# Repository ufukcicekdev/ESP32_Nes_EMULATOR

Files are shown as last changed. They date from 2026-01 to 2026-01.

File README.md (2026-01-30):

# 🎮 Anemoia-ESP32 S3 NES Console (Custom Build)

Bu proje, **ESP32-S3** mikrodenetleyicisi üzerinde çalışan, yüksek performanslı ve taşınabilir bir NES emülatörüdür. Orijinal [Anemoia-ESP32](https://github.com/Shim06/Anemoia-ESP32) projesi referans alınarak, özel donanım konfigürasyonuna ve **MAX98357A I2S DAC** ses sistemine göre optimize edilmiştir.

---

## 🚀 Donanım Özellikleri

* **İşlemci:** ESP32-S3 (N16R8 - 16MB Flash / 8MB Octal PSRAM desteği).
* **Ses Çözücü:** MAX98357A I2S DAC (44100Hz Örnekleme Hızı).
* **Depolama:** MicroSD Kart (Ayrı **FSPI** hattı ile çakışmasız hızlı erişim).
* **Ekran:** ILI9341 TFT LCD (**TFT_eSPI** kütüphanesi ile optimize).

---

## 🔌 Pin Bağlantı Şeması

Proje, ekran ve SD kartın aynı veri yolunda çakışmaması için **ayrı pin gruplarını** kullanacak şekilde yapılandırılmıştır.

### 🔊 Ses (MAX98357A I2S)
Ses kalitesini en üst düzeye çıkarmak için dijital I2S protokolü kullanılmıştır.

| MAX98357A Pini | ESP32-S3 GPIO |
| :--- | :--- |
| **BCLK** (Bit Clock) | **17** |
| **LRC** (WS / Clock) | **18** |
| **DOUT** (Data Out) | **21** |

### 💾 MicroSD Kart (FSPI Hattı)
SD kartın stabil çalışması için ayrılmış özel pinler tanımlanmıştır.

| SD Kart Pini | ESP32-S3 GPIO |
| :--- | :--- |
| **MOSI** | **14** |
| **MISO** | **3** |
| **SCLK** | **41** |
| **CS** | **42** |

### 🕹️ Kontrolcü & Buton Takımı
| Fonksiyon | GPIO | Fonksiyon | GPIO |
| :--- | :--- | :--- | :--- |
| **UP** | 16 | **START** | 1 |
| **DOWN** | 38 | **SELECT** | 2 |
| **LEFT** | 39 | **A** | 0 |
| **RIGHT** | 40 | **B** | 20 |

---

## ⚙️ Yazılım Kurulumu

### 1. TFT_eSPI Konfigürasyonu (Kritik!)
Ekran pinlerini tek tek ayarlamakla vakit kaybetmeyin:
* Repoda bulunan `User_Setup.h` dosyasını indirin.
* Bu dosyayı bilgisayarınızdaki `Documents/Arduino/libraries/TFT_eSPI/` klasörünün içine kopyalayıp eskisini değiştirin.
* Bu işlem, ekranınızın donanımla tam uyumlu çalışmasını sağlar.

### 2. Arduino IDE Ayarları
Yüksek FPS ve kararlılık için **Tools** menüsünden şu ayarları yapın:
* **Board:** `ESP32S3 Dev Module`
* **Flash Mode:** `QIO 80MHz`
* **PSRAM:** `OPI PSRAM` (Kartınız desteklemiyorsa Disabled yapın)
* **USB CDC On Boot:** `Disabled`
* **Core Debug Level:** `None`

---

## 🎮 Kullanım Notları

* **Oyun Yükleme:** `.nes` uzantılı oyun dosyalarınızı SD kartın ana dizinine (root) atın.
* **Menüye Dönüş:** Oyun sırasında **START + SELECT** (Pin 1 + Pin 2) tuşlarına aynı anda basarak ana menüye dönebilirsiniz.
* **Ses Kalitesi:** Varsayılan örnekleme hızı **44100Hz**'dir, retro oyunlarda en net ses deneyimini sunar.

---

## 📜 Kaynakça ve Teşekkür
Bu proje geliştirilirken [Anemoia-ESP32](https://github.com/Shim06/Anemoia-ESP32) kaynak kodları kullanılmış, donanımsal pin haritası ve I2S sürücüleri S3 mimarisi için özelleştirilmiştir.

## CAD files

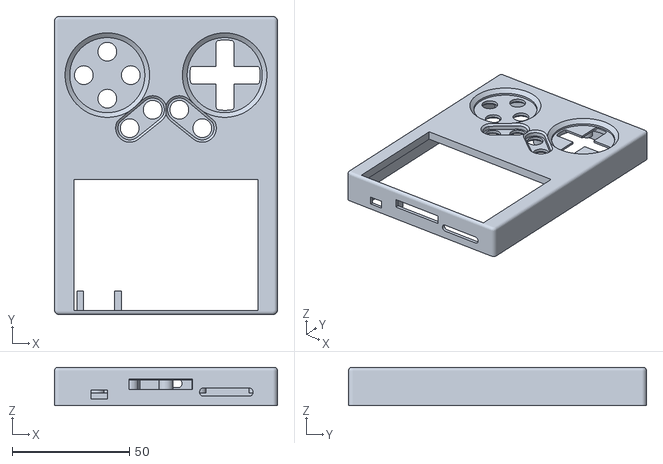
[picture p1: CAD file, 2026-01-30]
STL/anagövde.stl
95.0 x 127.0 x 16.4

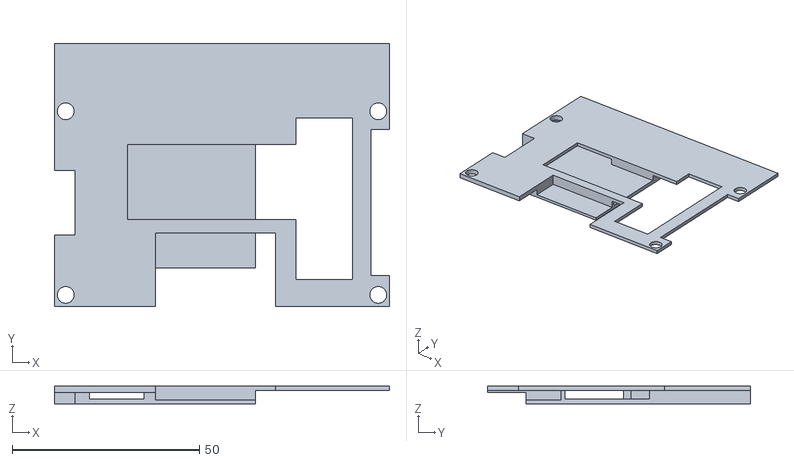
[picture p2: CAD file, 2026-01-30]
STL/ekranve bataryadestek.stl
89.4 x 70.1 x 4.80

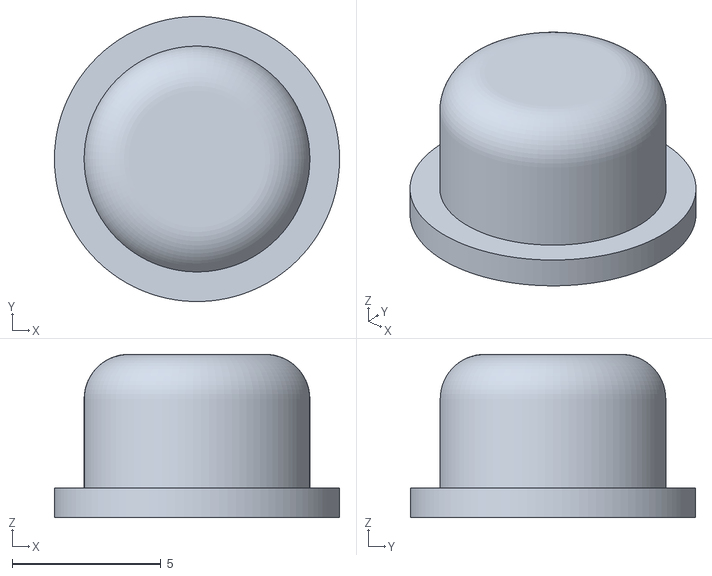
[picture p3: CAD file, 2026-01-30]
STL/buton.stl
9.60 x 9.60 x 5.50

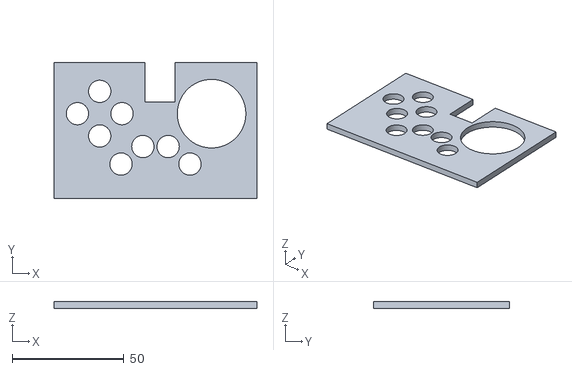
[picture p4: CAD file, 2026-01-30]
STL/3.stl
91.0 x 61.1 x 3.00

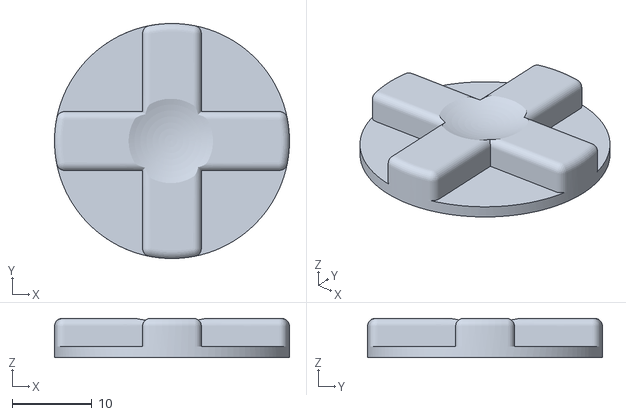
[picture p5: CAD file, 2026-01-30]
STL/dPad.stl
29.4 x 29.4 x 4.92

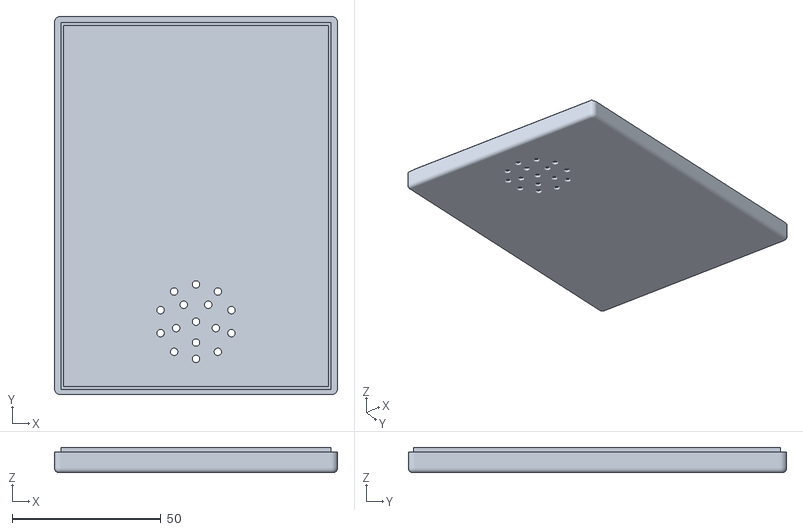
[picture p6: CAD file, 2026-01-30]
STL/arkakapak.stl
95.0 x 127.0 x 8.50

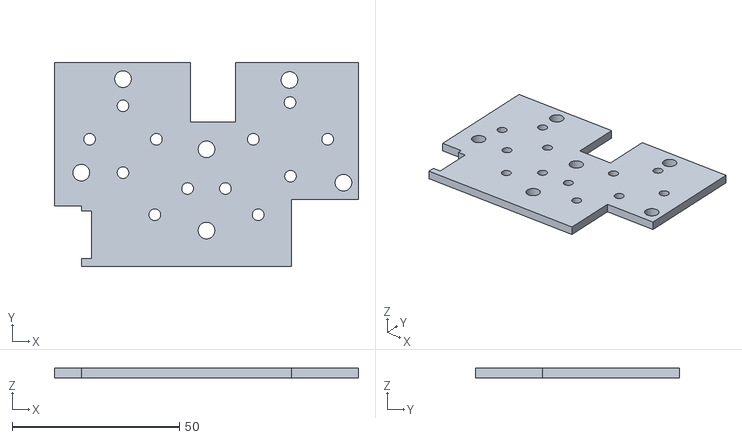
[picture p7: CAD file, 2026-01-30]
STL/2.stl
91.0 x 61.1 x 3.00

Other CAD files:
STL/1.stl

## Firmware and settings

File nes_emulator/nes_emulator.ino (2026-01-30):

#include <Arduino.h>
#include <SD.h>
#include <SPI.h>
#include <string>
#include <vector>

#include "src/core/bus.h"
#include "src/controller.h"
#include "config.h"
#include "driver/i2s.h"
#include "src/ui.h"

// --- SİSTEM AYARLARI (GLOBAL) ---
int globalVolume = 70;      // 0-100 arası
bool showFPS = true;        // FPS Göstergesi
uint16_t themeColor = TFT_CYAN;
float currentFPS = 0;

// --- DURUMLAR ---
enum AppState { STATE_DASHBOARD, STATE_FILE_LIST, STATE_BROWSER, STATE_SETTINGS, STATE_EMULATING };
AppState currentState = STATE_DASHBOARD;

SPIClass SD_SPI(HSPI);
static Bus nes; 
static Cartridge* cart = nullptr; 

std::vector<std::string> fileList;
std::string currentPath = "/";
int selectedIndex = 0;
int scrollOffset = 0;
int dashSelected = 0; 
int settingsSelected = 0; // Ayarlar menüsü seçimi
bool needsRedraw = true;

unsigned long lastInputTime = 0;
const int inputDelay = 150;

// --- 1. SES MOTORU (APU) ---
void setupI2SExternal() {
    i2s_driver_uninstall(I2S_NUM_0);
    i2s_config_t i2s_config = {
        .mode = (i2s_mode_t)(I2S_MODE_MASTER | I2S_MODE_TX),
        .sample_rate = 44100,
        .bits_per_sample = I2S_BITS_PER_SAMPLE_16BIT,
        .channel_format = I2S_CHANNEL_FMT_RIGHT_LEFT,
        .communication_format = I2S_COMM_FORMAT_STAND_I2S,
        .intr_alloc_flags = ESP_INTR_FLAG_LEVEL1 | ESP_INTR_FLAG_IRAM,
        // --- BURASI KRİTİK ---
        .dma_buf_count = 12,   // Buffer sayısını artırarak işlemciye nefes aldır
        .dma_buf_len = 256,   // Buffer boyunu küçülterek gecikmeyi (jitter) azalt
        .use_apll = false,
        .tx_desc_auto_clear = true
    };
    i2s_driver_install(I2S_NUM_0, &i2s_config, 0, NULL);
    
    i2s_pin_config_t pin_config = { 
        .bck_io_num = I2S_BCLK_PIN, 
        .ws_io_num = I2S_LRC_PIN, 
        .data_out_num = I2S_DOUT_PIN, 
        .data_in_num = I2S_PIN_NO_CHANGE 
    };
    i2s_set_pin(I2S_NUM_0, &pin_config);
    i2s_start(I2S_NUM_0); 
    i2s_zero_dma_buffer(I2S_NUM_0);
}

void apuTask(void* param) {
    Apu2A03* apu = (Apu2A03*)param;
    size_t bytes_written;
    i2s_zero_dma_buffer(I2S_NUM_0);

    while (true) {
        for (int i = 0; i < AUDIO_BUFFER_SIZE; i++) {
            // NES Clock Hızı: Eğer ses çok cızırtılıysa 38-42 arasını dene.
            // Bu sayı saniyede kaç NES cycle'ının bir ses örneğine (sample) 
            // dönüşeceğini belirler.
            for(int j = 0; j < 40; j++) {
                apu->clock(); 
            }
            apu->generateSample(); 
        }

        // I2S'e yazarken portMAX_DELAY yerine küçük bir timeout ver
        i2s_write(I2S_NUM_0, 
                  Apu2A03::audio_buffer, 
                  sizeof(Apu2A03::audio_buffer), 
                  &bytes_written, 
                  pdMS_TO_TICKS(10)); 
        
        yield(); 
    }
}
// --- 2. DOSYA YÖNETİMİ ---
void scanDirectory(std::string path, bool sadeceOyun) {
    fileList.clear();
    selectedIndex = 0; scrollOffset = 0;
    if (path != "/") fileList.push_back("..");
    File root = SD.open(path.c_str());
    if(!root) return;
    File file = root.openNextFile();
    while (file) {
        std::string fn = file.name();
        if (fn[0] != '.' && fn.find("_.") == std::string::npos) {
            if (sadeceOyun) { if (fn.find(".nes") != std::string::npos) fileList.push_back(fn); }
            else { fileList.push_back(file.isDirectory() ? "[" + fn + "]" : fn); }
        }
        file = root.openNextFile();
    }
    root.close();
}

// --- 3. EMÜLASYON VE KONTROL ---
void forceExitEmulation(TaskHandle_t &apu_h) {
    if (apu_h != NULL) { vTaskDelete(apu_h); apu_h = NULL; }
    i2s_zero_dma_buffer(I2S_NUM_0);
    if (cart != nullptr) { delete cart; cart = nullptr; }
    digitalWrite(SD_CS_PIN, HIGH);
    lastInputTime = millis(); 
    needsRedraw = true;
}

void emulate(std::string fullPath) {
    cart = new Cartridge(fullPath.c_str());
    if (!cart) return;
    
    UI::clearScreen(); 
    nes.connectScreen(&screen); 
    nes.insertCartridge(cart);
    nes.reset();

    TaskHandle_t apu_h = NULL;
    xTaskCreatePinnedToCore(apuTask, "apuTask", 2028, &nes.cpu.apu, 10, &apu_h, 0);

    unsigned long lastFrameTime = micros();

    while (true) {
        uint16_t in = controllerRead();
        nes.controller = (uint8_t)in;

        // --- OYUN İÇİ SES KONTROLÜ (SELECT + UP/DOWN) ---
        if (in & CONTROLLER::Select) {
            if (in & CONTROLLER::Up && globalVolume < 100) { globalVolume += 2; delay(20); }
            if (in & CONTROLLER::Down && globalVolume > 0) { globalVolume -= 2; delay(20); }
        }

        // FPS Hesapla
        unsigned long now = micros();
        currentFPS = 1000000.0 / (now - lastFrameTime);
        lastFrameTime = now;

        if (in & CONTROLLER::GameMenu) {
            vTaskSuspend(apu_h);
            int mSel = 0; 
            UI::drawPauseMenu(mSel); 
            delay(250);
            bool menuOn = true;
            while(menuOn) {
                uint16_t mi = controllerRead();
                if (mi & CONTROLLER::Up) { mSel--; if(mSel<0) mSel=3; UI::drawPauseMenu(mSel); delay(150); }
                if (mi & CONTROLLER::Down) { mSel++; if(mSel>3) mSel=0; UI::drawPauseMenu(mSel); delay(150); }
                if (mi & CONTROLLER::A) {
                    if (mSel == 0) menuOn = false;
                    if (mSel == 1) { nes.saveState(); menuOn = false; }
                    if (mSel == 2) { nes.loadState(); menuOn = false; }
                    if (mSel == 3) { forceExitEmulation(apu_h); currentState = STATE_FILE_LIST; return; }
                }
                yield();
            }
            UI::clearScreen(); 
            vTaskResume(apu_h);
        }

        if (in & CONTROLLER::Menu) { forceExitEmulation(apu_h); currentState = STATE_DASHBOARD; return; }
        
        nes.clock(); 
        
        if(showFPS) UI::drawFPS(currentFPS);
    }
}

// --- 4. HANDLER FONKSİYONLARI ---
void handleDashboard() {
    uint16_t input = controllerRead();
    if (millis() - lastInputTime < inputDelay) return;
    if (input & CONTROLLER::Left && dashSelected > 0) { dashSelected--; needsRedraw = true; lastInputTime = millis(); }
    else if (input & CONTROLLER::Right && dashSelected < 2) { dashSelected++; needsRedraw = true; lastInputTime = millis(); }
    
    if (needsRedraw) { UI::drawDashboard(dashSelected); needsRedraw = false; }
    
    if (input & CONTROLLER::A) {
        lastInputTime = millis();
        if (dashSelected == 0) { currentPath = "/NES/"; scanDirectory(currentPath, true); currentState = STATE_FILE_LIST; }
        else if (dashSelected == 1) { currentPath = "/"; scanDirectory(currentPath, false); currentState = STATE_BROWSER; }
        else { currentState = STATE_SETTINGS; settingsSelected = 0; }
        needsRedraw = true;
    }
}

void handleSettings() {
    uint16_t in = controllerRead();
    if (millis() - lastInputTime < inputDelay) return;

    if (in & CONTROLLER::Up && settingsSelected > 0) { settingsSelected--; needsRedraw = true; lastInputTime = millis(); }
    if (in & CONTROLLER::Down && settingsSelected < 3) { settingsSelected++; needsRedraw = true; lastInputTime = millis(); }

    // Değer değiştirme (Sağ/Sol)
    if (settingsSelected == 0) { // Ses
        if (in & CONTROLLER::Right && globalVolume < 100) { globalVolume += 5; needsRedraw = true; lastInputTime = millis(); }
        if (in & CONTROLLER::Left && globalVolume > 0) { globalVolume -= 5; needsRedraw = true; lastInputTime = millis(); }
    }
    if (settingsSelected == 1) { // FPS
        if ((in & CONTROLLER::Right || in & CONTROLLER::Left)) { showFPS = !showFPS; needsRedraw = true; lastInputTime = millis(); }
    }

    if (in & CONTROLLER::B || (settingsSelected == 3 && in & CONTROLLER::A)) {
        currentState = STATE_DASHBOARD; needsRedraw = true; lastInputTime = millis(); return;
    }

    if (needsRedraw) {
        UI::drawSettings(settingsSelected, globalVolume, showFPS, themeColor);
        needsRedraw = false;
    }
}

void handleCommonList(bool isGameList) {
    uint16_t in = controllerRead();
    if (millis() - lastInputTime < inputDelay) return;
    if (in & CONTROLLER::Up && selectedIndex > 0) { selectedIndex--; if (selectedIndex < scrollOffset) scrollOffset = selectedIndex; needsRedraw = true; lastInputTime = millis(); }
    else if (in & CONTROLLER::Down && selectedIndex < (int)fileList.size()-1) { selectedIndex++; if (selectedIndex >= scrollOffset + 9) scrollOffset++; needsRedraw = true; lastInputTime = millis(); }
    if (in & CONTROLLER::B) { currentState = STATE_DASHBOARD; needsRedraw = true; lastInputTime = millis(); return; }
    
    if (in & CONTROLLER::A) {
        lastInputTime = millis();
        std::string sel = fileList[selectedIndex];
        if (sel == "..") {
            size_t last = currentPath.find_last_of('/', currentPath.length()-2);
            currentPath = currentPath.substr(0, last+1); scanDirectory(currentPath, isGameList);
            needsRedraw = true;
        } else if (sel[0] == '[') {
            currentPath += sel.substr(1, sel.length()-2) + "/"; scanDirectory(currentPath, isGameList);
            needsRedraw = true;
        } else if (isGameList && sel.find(".nes") != std::string::npos) {
            emulate(currentPath + sel);
            needsRedraw = true;
        }
    }
    
    if (needsRedraw) { 
        UI::drawList(isGameList ? "@withufuk OYUNLAR" : "@withufuk DOSYALAR", fileList, selectedIndex, scrollOffset); 
        needsRedraw = false; 
    }
}

// --- 5. SETUP VE LOOP ---
void setup() {
    Serial.begin(115200); 
    psramInit();
    UI::init(); 
    UI::drawBootScreen();
    setupI2SExternal();
    SD_SPI.begin(SD_SCLK_PIN, SD_MISO_PIN, SD_MOSI_PIN, SD_CS_PIN);
    SD.begin(SD_CS_PIN, SD_SPI, 40000000);
    initController();
}

void loop() {
    switch(currentState) {
        case STATE_DASHBOARD: handleDashboard(); break;
        case STATE_FILE_LIST: handleCommonList(true); break;
        case STATE_BROWSER:   handleCommonList(false); break;
        case STATE_SETTINGS:  handleSettings(); break;
    }
}

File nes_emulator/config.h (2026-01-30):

#ifndef CONFIG_H
#define CONFIG_H


// config.h içine uygun bir yere ekle
extern int globalVolume;       // 0-100 arası
extern bool showFPS;           // FPS sayacı açık mı?
extern uint16_t themeColor;    // Seçili tema rengi

// Kontrolcü Tipi (Buton kullanmadığın için 0 kalsın)
#define CONTROLLER_TYPE 0

// MicroSD kart hızı (Eski kartlar için 4MHz en güvenlisidir)
#define SD_FREQ 4000000

// Ekran Konfigürasyonu
#define SCREEN_ROTATION 3
#define SCREEN_SWAP_BYTES false



// --- SD KART FSPI PİNLERİ (Ayırdığın Hat) ---
#define SD_MOSI_PIN 14
#define SD_MISO_PIN 3
#define SD_SCLK_PIN 41
#define SD_CS_PIN   42

// Hata veren kontrolcü pinlerini etkisiz hale getiriyoruz
#define CONTROLLER_NES_LATCH -1
#define CONTROLLER_NES_DATA  -1
#define CONTROLLER_NES_CLK   -1
#define CONTROLLER_SNES_LATCH -1
#define CONTROLLER_SNES_DATA  -1
#define CONTROLLER_SNES_CLK   -1
#define CONTROLLER_PSX_ATTENTION -1
#define CONTROLLER_PSX_COMMAND   -1
#define CONTROLLER_PSX_CLK       -1
#define CONTROLLER_PSX_DATA      -1

// Butonlar (Şimdilik devre dışı)
#define A_BUTTON 0
#define B_BUTTON 20
#define UP_BUTTON 16
#define DOWN_BUTTON 38
#define LEFT_BUTTON 39
#define RIGHT_BUTTON 40
#define START_BUTTON 1
#define SELECT_BUTTON 2
#define MENU 5
#define GAME_MENU 6
#define GAME_MENU1 7
#define GAME_MENU2 47




// --- I2S SES PİNLERİ (MAX98357A) ---
#define I2S_BCLK_PIN 17   // Bit Clock
#define I2S_LRC_PIN  18   // Left/Right Clock (WS)
#define I2S_DOUT_PIN 21  // Data Out


#define SAMPLE_RATE 44100
#define FRAMESKIP
#define DEBUG true
#endif

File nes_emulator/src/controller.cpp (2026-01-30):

#include "controller.h"
#include "../config.h"
#include <Arduino.h>

uint16_t controllerRead() // uint16_t olarak güncellendi
{
    uint16_t state = 0;

#if CONTROLLER_TYPE == 0
    // Standart NES Butonları
    if (digitalRead(A_BUTTON)      == LOW) state |= CONTROLLER::A;
    if (digitalRead(B_BUTTON)      == LOW) state |= CONTROLLER::B;
    if (digitalRead(SELECT_BUTTON) == LOW) state |= CONTROLLER::Select;
    if (digitalRead(START_BUTTON)  == LOW) state |= CONTROLLER::Start;
    if (digitalRead(UP_BUTTON)     == LOW) state |= CONTROLLER::Up;
    if (digitalRead(DOWN_BUTTON)   == LOW) state |= CONTROLLER::Down;
    if (digitalRead(LEFT_BUTTON)   == LOW) state |= CONTROLLER::Left;
    if (digitalRead(RIGHT_BUTTON)  == LOW) state |= CONTROLLER::Right;

    // Yeni Fonksiyon Butonları
    if (digitalRead(MENU)       == LOW) state |= CONTROLLER::Menu;
    if (digitalRead(GAME_MENU)  == LOW) state |= CONTROLLER::GameMenu;
    if (digitalRead(GAME_MENU1) == LOW) state |= CONTROLLER::GameMenu1;
    if (digitalRead(GAME_MENU2) == LOW) state |= CONTROLLER::GameMenu2;

#elif CONTROLLER_TYPE == 1
    state = NESControllerRead(); // Gerekirse bu fonksiyonları da 16 bit yapabilirsin
#endif

    return state;
}

bool isDownPressed(CONTROLLER button)
{
    return (controllerRead() & button) != 0;
}

void initController()
{
#if CONTROLLER_TYPE == 0
    // Mevcut Pinler
    pinMode(A_BUTTON, INPUT_PULLUP);
    pinMode(B_BUTTON, INPUT_PULLUP);
    pinMode(LEFT_BUTTON, INPUT_PULLUP);
    pinMode(RIGHT_BUTTON, INPUT_PULLUP);
    pinMode(UP_BUTTON, INPUT_PULLUP);
    pinMode(DOWN_BUTTON, INPUT_PULLUP);
    pinMode(START_BUTTON, INPUT_PULLUP);
    pinMode(SELECT_BUTTON, INPUT_PULLUP);

    // Yeni Eklenen Fonksiyon Butonları
    pinMode(MENU, INPUT_PULLUP);
    pinMode(GAME_MENU, INPUT_PULLUP);
    pinMode(GAME_MENU1, INPUT_PULLUP);
    pinMode(GAME_MENU2, INPUT_PULLUP);
#endif
    // Diğer controller tipleri (NES, SNES, PSX) için gerekirse ekleme yapılabilir
}
